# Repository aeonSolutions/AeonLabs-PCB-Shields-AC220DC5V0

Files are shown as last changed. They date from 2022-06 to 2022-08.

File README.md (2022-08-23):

# AeonLabs PCB Shields AC 85V-220V to DC 5.0V
 This is a pcb design for a AC220V 1A to DC 5V0 converter. With 220V fuse for increased safety. Suitable as a add-on design for any other KiCad project.

*Don't forget to LIKE , SHARE and subscribe the free whatsApp group* and if you liked this PCB consider buying me a cup of coffee. Links below.




### Status
  revision 1.1 fully tested and working.

If you already tested this PCB send me a message. Thank you

## Revisions
- revision 1.1 
  - bug track corrections
  - added overcurrent protection 
 
## Download options
Download this repository if you need the KiCad Files or, download the Gerber files in the release section of this repository

## Liked it ? Get a Free PCB for yourself
Send me your Device or hardware and i will design a custom PCB for it. Free of charge. Contact-me on WhatsApp or email for more info. 

## Q&A WhatsApp Group
If you have any Questions or simply  like this kind of projects and want to stay updated with the latest research ideas and prototypes during the day and week, join the WhatsApp Group
[A.I. Things](https://chat.whatsapp.com/FkNC7u83kuy2QRA5sqjBVg)

## Fully assembled PCB
Alternatively, and if you do not want to build a PCB by yourself and like to buy one, you can do it here:

(https://www.tindie.com/stores/aeonlabs/)

The price will be around 30eur plus postage fees.
(I will also deliver the assembled PCB with all the components in place at a fair aditonal cost).

This PCB is a #direct fit #replacement of the one found on the internet at sale. For example here: https://s.click.aliexpress.com/e/_9wRPxz

#### Be supportive of my dedication and work towards technology education and buy me a coffee. Link below.

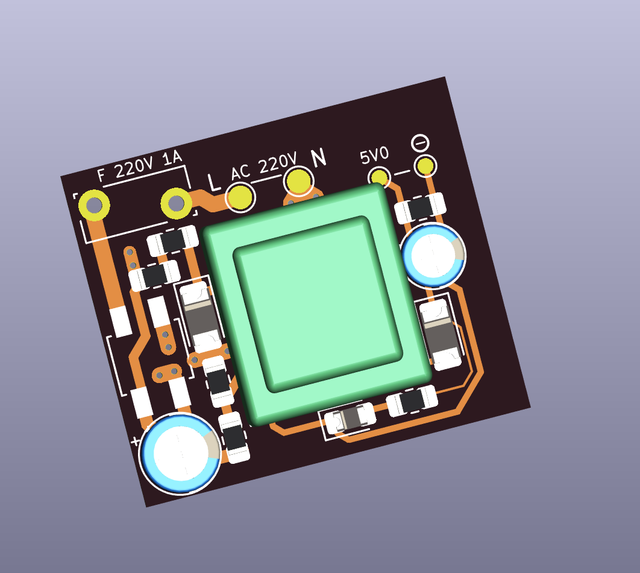
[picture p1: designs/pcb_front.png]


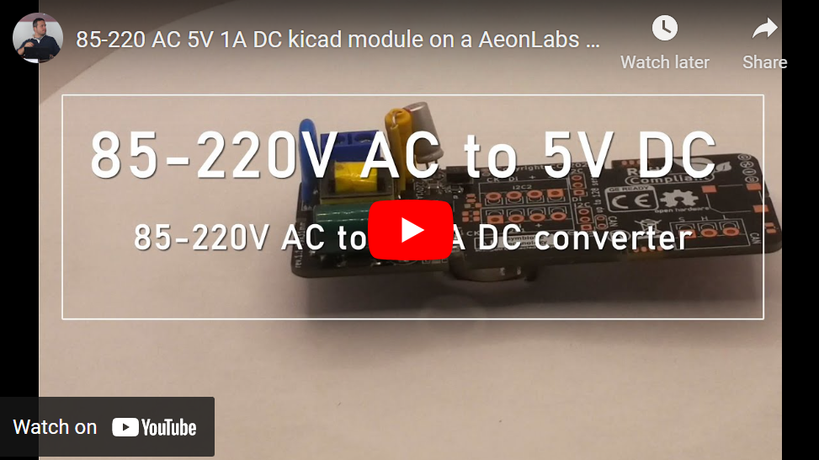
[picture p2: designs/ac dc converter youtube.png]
(https://youtu.be/YiTJY-2XoHM)


view me testing this pcb module with a multimeter on youtube, [here](https://youtu.be/aK8yDyUbOkI)

________________________________________________________________________________________________________________

## PCB Parts list
- [Capacitor 2.2uF SMD](https://s.click.aliexpress.com/e/_AVdmzr)
- [Resistor SMD ](https://s.click.aliexpress.com/e/_A7OXrR)
- [EE10-A1 switching power supply transformer 220V to 5-12V](https://s.click.aliexpress.com/e/_DDHkwsf)
- [4.7uF 400V Electrolitic Capacitor](https://s.click.aliexpress.com/e/_DlkOyWT)
- [390uF 6.3V Solid Electrolitic Capacitor](https://s.click.aliexpress.com/e/_DkZ4zmf)
- [SS36 rectifier Diode](https://s.click.aliexpress.com/e/_DFlMjfv)
- [MB10F 4 Diode Bridge Rectifier](https://s.click.aliexpress.com/e/_DcfTow3)
- [HT2812H AC DC 5W charging](https://s.click.aliexpress.com/e/_Dk6dCGB)

## Firmware Download 
one can use the PCB in the repository [AeonLabs-MCU-Burner-USB-to-UART-TTL](https://github.com/aeonSolutions/AeonLabs-MCU-Burner-USB-to-UART-TTL) to program the ESP32 WROOM32 MCU on this PCB.

______________________________________________________________________________________________________________________________

### License
2022 Creative Commons Attribution-NonCommercial-ShareAlike 4.0 International

https://creativecommons.org/licenses/by-nc-sa/4.0/

### Own a copy of this work
if you like to own a copy of this work, you can buy it as a NFT or Ethereum. contact me for more details at mtpsilva@gmail.com
________________________________________________________________________________________________________________
## [Go back to main catalogue page](https://github.com/aeonSolutions/PCB-Prototyping-Catalogue)
________________________________________________________________________________________________________________

### Share this PCB board files
[](https://twitter.com/intent/tweet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)

<a href="https://stackexchange.com/users/18907312/miguel-silva">profile for Miguel Silva on Stack Exchange, a network of free, community-driven Q&A sites</a>

### Be supportive of my dedication and work towards technology education and buy me a coffee

[](https://www.buymeacoffee.com/migueltomas)

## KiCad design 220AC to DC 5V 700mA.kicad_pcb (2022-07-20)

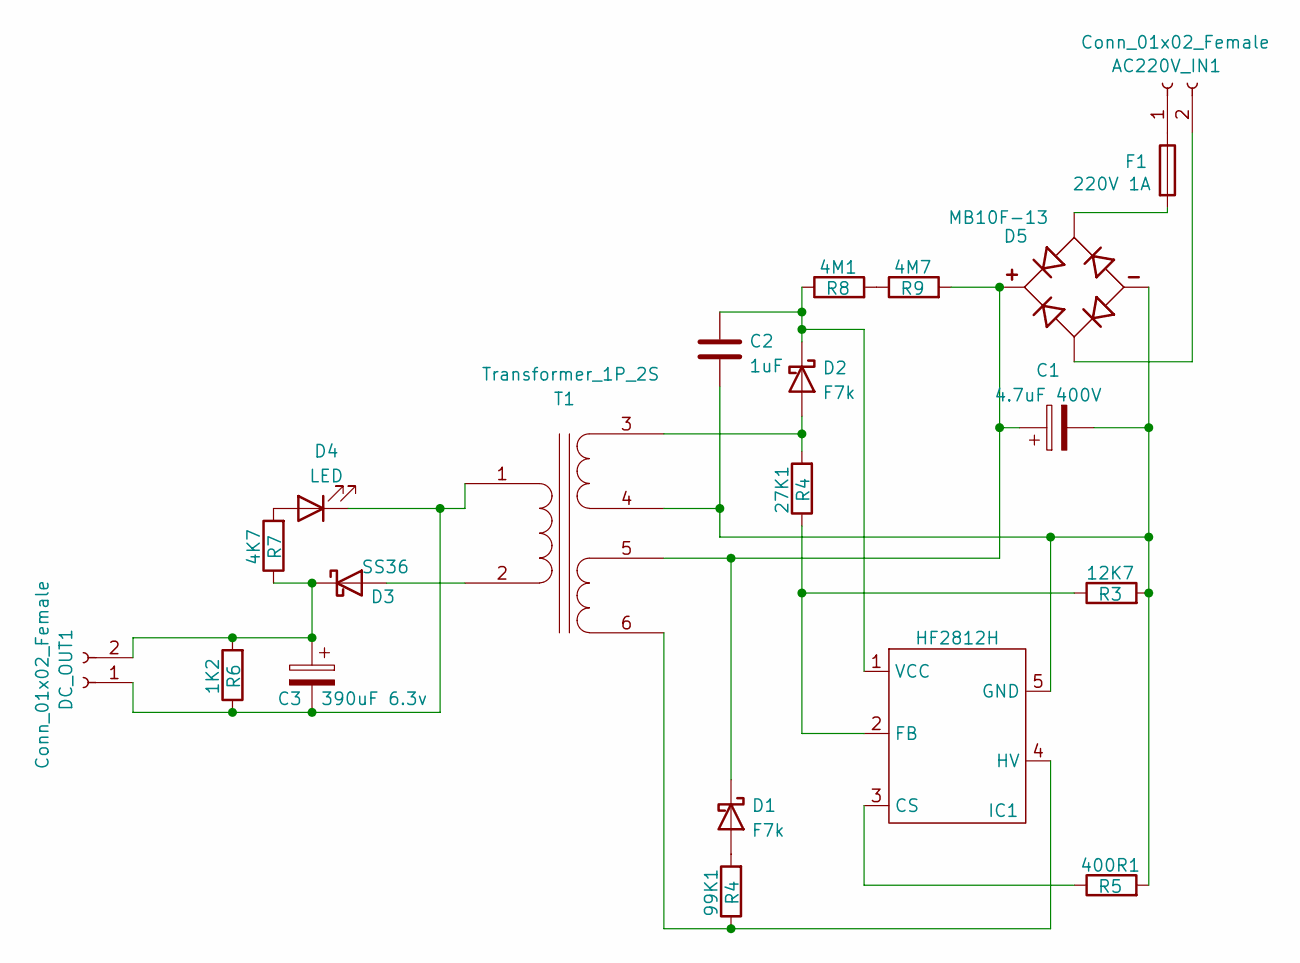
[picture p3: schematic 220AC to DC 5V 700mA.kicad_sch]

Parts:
1K2: R6; R_0805_2012Metric_Pad1.20x1.40mm_HandSolder
4K7: R7; R_0805_2012Metric_Pad1.20x1.40mm_HandSolder
4M1: R8; R_0805_2012Metric_Pad1.20x1.40mm_HandSolder
4M7: R9; R_0805_2012Metric_Pad1.20x1.40mm_HandSolder
12K7: R3; R_0805_2012Metric_Pad1.20x1.40mm_HandSolder
27K1, 99K1: R4; R_0805_2012Metric_Pad1.20x1.40mm_HandSolder
400R1: R5; R_0805_2012Metric_Pad1.20x1.40mm_HandSolder
AC220V_IN1: Conn_01x02_Female; TestPoint_Pad_D1.5mm x2
C1: 4.7uF 400V; CP_Radial_D5.0mm_P2.00mm
C2: 1uF; C_0805_2012Metric_Pad1.18x1.45mm_HandSolder
C3: 390uF 6.3v; CP_Radial_D4.0mm_P1.50mm
D1, D2: F7k; D_1206_3216Metric_Pad1.42x1.75mm_HandSolder
D3: SS36; D_1206_3216Metric_Pad1.42x1.75mm_HandSolder
D4: LED; D_0805_2012Metric_Pad1.15x1.40mm_HandSolder
D5: MB10F-13; DIOB_MB10F-13; PARTREV 3 - 2
DC_OUT1: Conn_01x02_Female; TestPoint_Pad_D1.0mm x2
F1: 220V 1A; Fuse_Bourns_MF-RG300
IC1: HF2812H; SOP5
T1: Transformer_1P_2S; Transformer_EE10-A1 11.5x12.5mm

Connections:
unnamed: 1K2.1, C3.2, D4.1 (K), DC_OUT1.1, T1.1 (AA)
unnamed: 1K2.2, 4K7.1, C3.1, D3.1 (K), DC_OUT1.2
unnamed: 4K7.2, D4.2 (A)
unnamed: 4M1.1, C2.1, D2.1 (K), IC1.1 (VCC)
unnamed: 4M1.2, 4M7.1
unnamed: 4M7.2, C1.1, D1.1 (K), D5.1, T1.5 (SC)
unnamed: 12K7.1, 27K1.1, IC1.2 (FB)
unnamed: 12K7.2, 400R1.2, C1.2, C2.2, D5.3, IC1.5 (GND), T1.4 (SB)
unnamed: 27K1.2, D2.2 (A), T1.3 (SA)
unnamed: 99K1.1, IC1.4 (HV), T1.6 (SD)
unnamed: 99K1.2, D1.2 (A)
unnamed: 400R1.1, IC1.3 (CS)
unnamed: AC220V_IN1.1, F1.1
unnamed: AC220V_IN1.2, D5.4
unnamed: D3.2 (A), T1.2 (AB)
unnamed: D5.2, F1.2

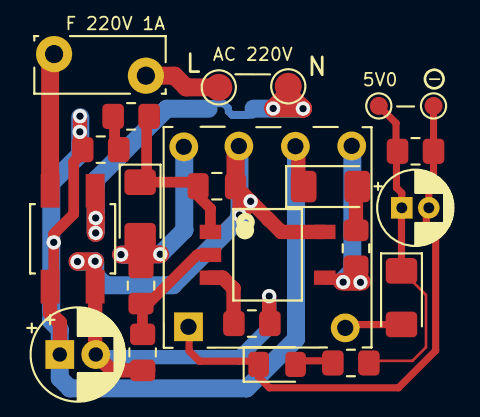
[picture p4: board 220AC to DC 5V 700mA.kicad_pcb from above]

Board: 2 copper layers, 21 parts (0 on the bottom side), 16 nets.

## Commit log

2022-06-25 rev 1.0
    [220AC to DC 5V 700mA.kicad_pcb, 220AC to DC 5V 700mA.kicad_sch]
2022-07-20 rev. update
    bug track correction ; added overcurrent protection
    [220AC to DC 5V 700mA.kicad_pcb]
